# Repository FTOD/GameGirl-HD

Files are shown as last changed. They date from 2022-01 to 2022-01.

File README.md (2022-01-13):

GameGirl Hardware Development
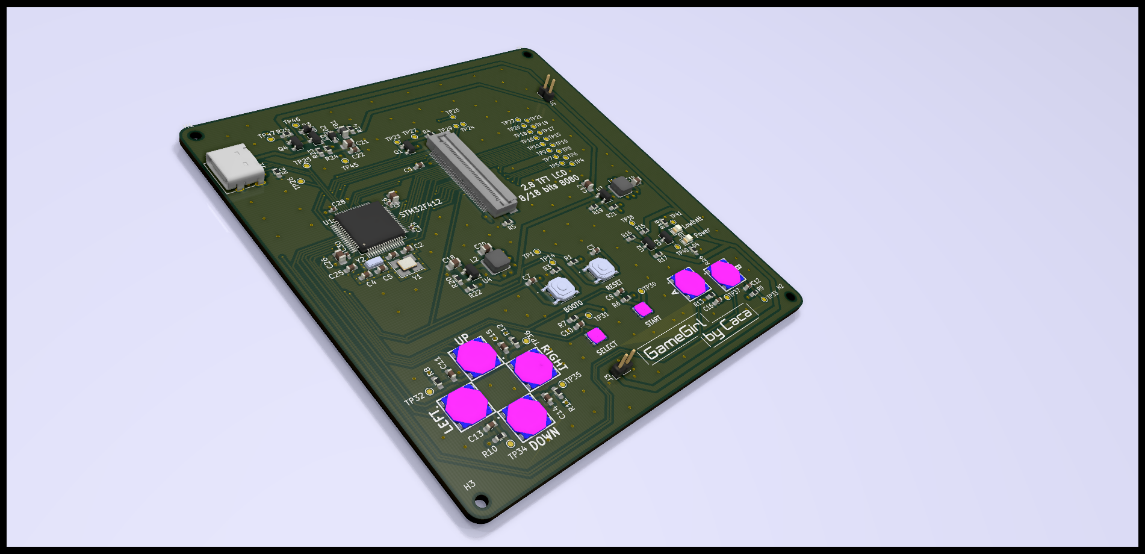
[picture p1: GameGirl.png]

[Schematics as PDF](schematics.pdf)
## To do better in the next version:
-   Impedance matching of D+/D- lines of USB
-   Use Lipo or Li-ion battery with embedded charger circuit
-   Embed the On-Off switch (some PMIC may have this kind of feature with tactile switches)
## License

Copyright (c) Caca 2021-1.
This source and all design files in the GameGirl project: https://github.com/FTOD/GameGirl-HD describe Open Hardware and is licensed under the CERN-OHL-P
v2
You may redistribute and modify this documentation and make products
using it under the terms of the CERN-OHL-P v2 (https:/cern.ch/cern-ohl).
This documentation is distributed WITHOUT ANY EXPRESS OR IMPLIED
WARRANTY, INCLUDING OF MERCHANTABILITY, SATISFACTORY QUALITY
AND FITNESS FOR A PARTICULAR PURPOSE. Please see the CERN-OHL-P v2
for applicable conditions

please refer to [cern_ohl_p_v2_howto.pdf](cern_ohl_p_v2_howto.pdf) for how to deal with this license.

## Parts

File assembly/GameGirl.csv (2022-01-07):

Designator | Quantity | Value | Footprint | LCSC Part#
C1, C2, C4, C5, | 4 | 20pF | 603 | C1648
C9, C10, C11, C12, C13, C14, C15, C16, | 8 | 10nF | 603 | C57112
C3, C7, | 2 | 100pF | 603 | C14858
C6, C17, C18, | 3 | 4.7uF | 805 | C1779
C8, | 1 | 1uF | 603 | C28323
C19, C20, C21, C26, | 4 | 10uF | 805 | C440198
C22, C25, | 2 | 100nF | 603 | C14663
C27, C28, C29, C30, | 4 | 100nF | 402 | C307331
D1 | 2 | LED | 805 | C2296
D4 | 2 | LED | 805 | C2297
D2, D3, | 2 | D_Shockley | SOD-323 | C191023
FB1, | 1 | GZ2012D601TF | 805 | C1017
J1, | 1 | USB_C(U262-161N-4BVC11) | USB-3.1-SMD | C319148
J2, | 1 | FH28-40S-0.5SH(07) | FPC-SMD | C424677
L1, L2, | 2 | 2.2uH | IND-SMD | C136245
Q1, Q2, | 2 | AO3400(NMOS) | SOT-23 | C20917
Q3, Q4, | 2 | AO3401 | SOT-23 | C15127
R1, R3, R6, R7, R8, R9, R10, R11, R12, R13, R14, R16, R23, R25, | 14 | 10K | 603 | C25804
R2, | 1 | 5.1K | 603 | C23186
R4, | 1 | 10R | 603 | C22859
R5, | 1 | 20K | 603 | C4184
R15, | 1 | 3.3K | 603 | C22978
R17, | 1 | 1K | 603 | C21190
R18, R26, | 2 | 100R | 603 | C22775
R19, R20, | 2 | 100K | 603 | C25803
R21, | 1 | 430K | 603 | C25969
R22, | 1 | 200K | 603 | C25811
R24, | 1 | 4.7K | 603 | C23162
SW1, SW2, | 2 | TS-1187 | SMD-SW-4_5.1x5.1x1.5 | C318884
SW3, SW4, | 2 | SKSHAAE010 | SW-SMD | C262415
SW5, SW6, SW7, SW8, SW9, SW10, | 6 | SKRRAAE010 | KEY-SMD | C97437
U1, | 1 | STM32F412RET6 | LQFP-64_10.0x10.0x0.5P | C89374
U2, | 1 | TL431 | SOT-23-3 | C350683
U3, U4, | 2 | TLV62569DBV | SOT-23-5 | C141836
Y1, | 1 | X322525-25MHz 12pF | SMD-3225_4P | C9006
Y2, | 1 | FC135-32.768kHz 12.5pF | SMD-3215_2P | C32346

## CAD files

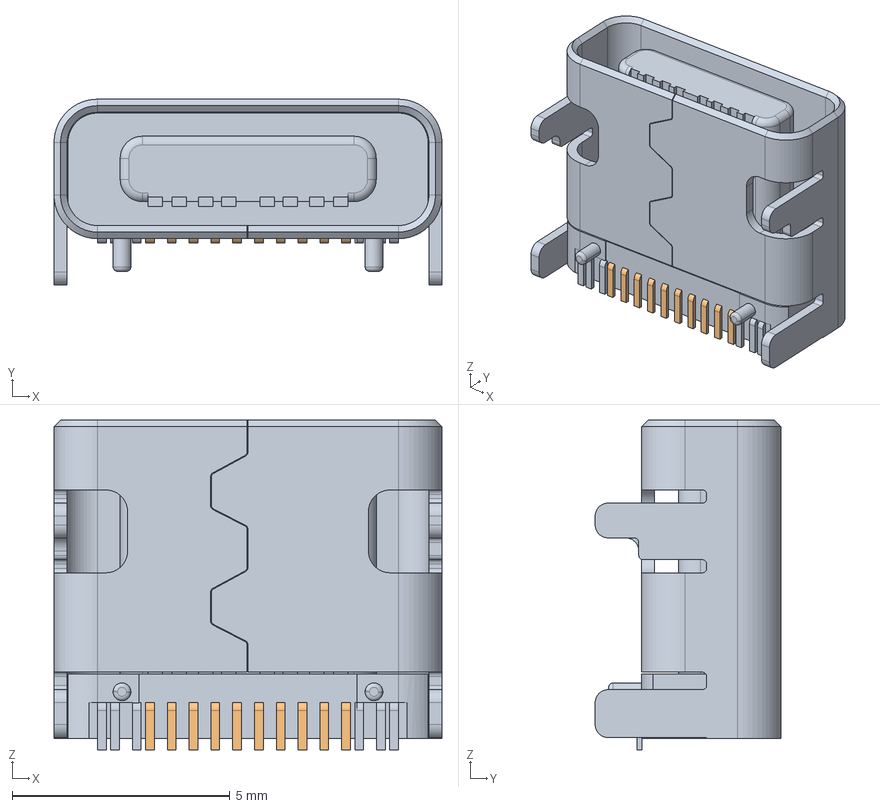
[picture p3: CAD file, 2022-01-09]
3D/u262-161n-4bvc11.stp
8.90 x 4.26 x 7.56 mm

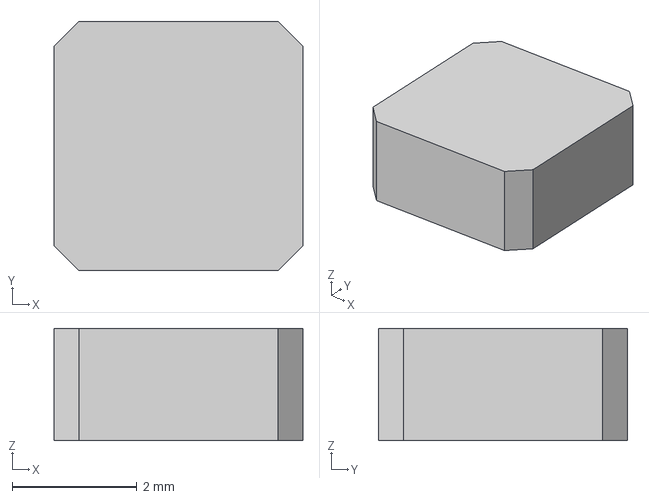
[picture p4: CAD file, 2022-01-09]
3D/VLCF4020.step
4.00 x 4.00 x 1.80 mm

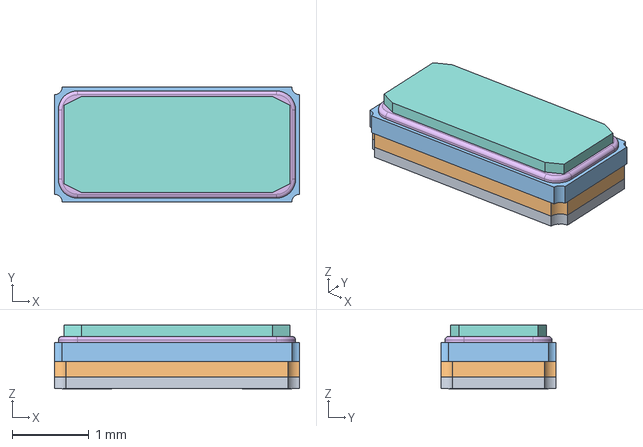
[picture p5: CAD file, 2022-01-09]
FC-135.step
3.20 x 1.50 x 0.831 mm

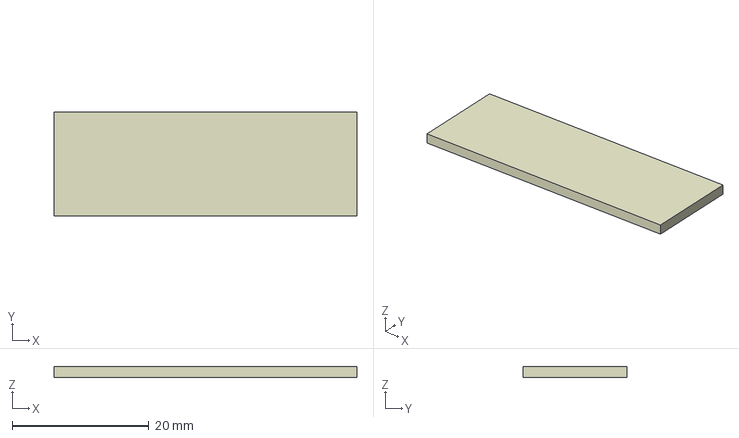
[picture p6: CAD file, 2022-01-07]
3D/Pcb.step
44.3 x 15.2 x 1.58 mm

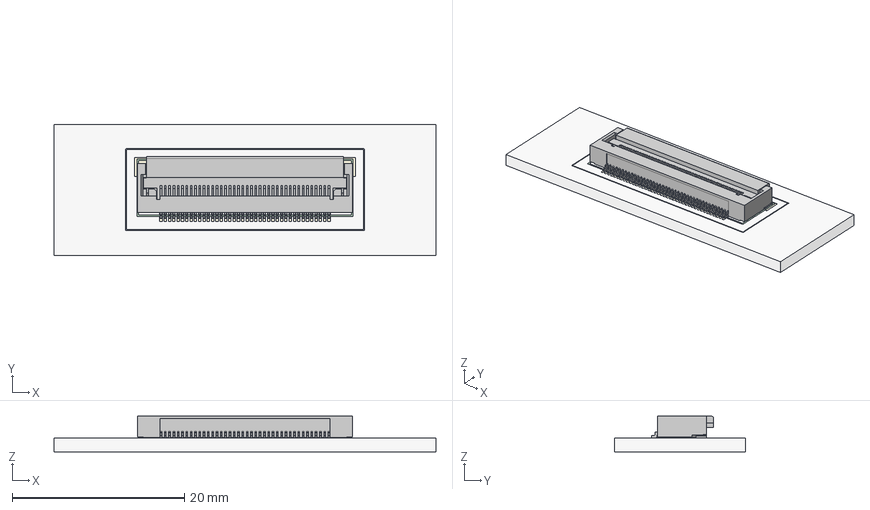
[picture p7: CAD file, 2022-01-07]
3D/40PFFP-worked.FCStd
44.3 x 15.2 x 4.14 mm
FCrtYd
FFab
FrontSilk
TopPads
Pcb
FH28-40S-0.5SH_Èª

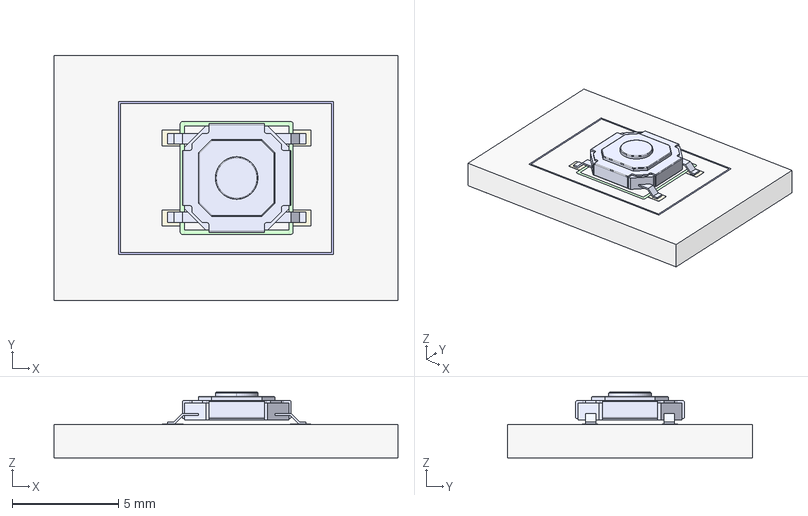
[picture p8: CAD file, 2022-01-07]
3D/TS-1187A-B-A-B-worked.FCStd
16.2 x 11.5 x 3.09 mm
FCrtYd
FFab
FrontSilk
TopPads
Pcb
TS-1187A-B-A-B

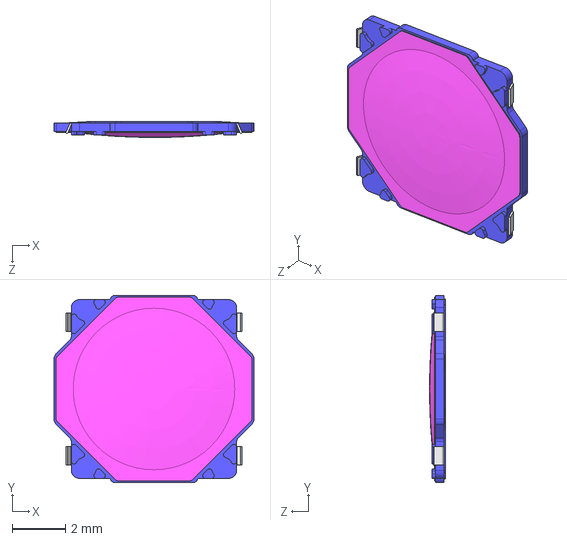
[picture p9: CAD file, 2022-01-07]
3D/SKRRAA.STEP
7.50 x 7.03 x 0.6 mm

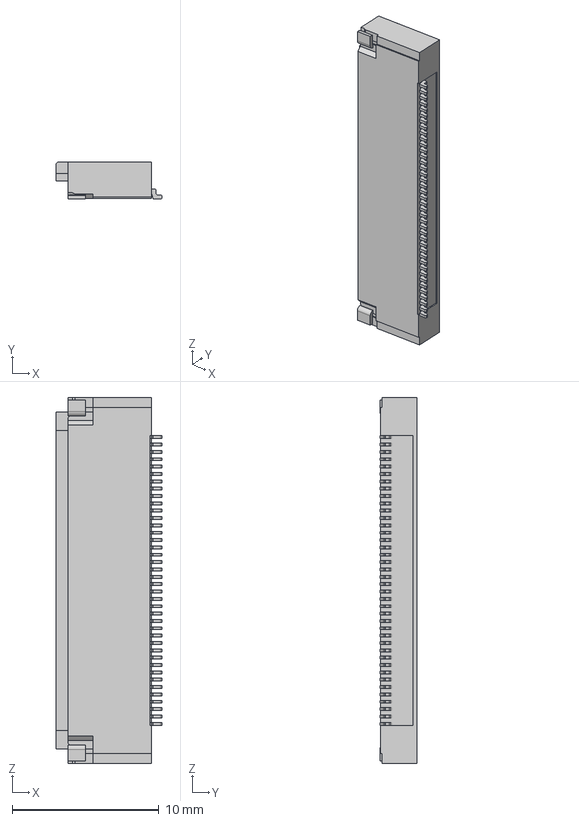
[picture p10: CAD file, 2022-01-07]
3D/FH28-40S-0.5SH.stp
7.20 x 2.55 x 24.9 mm

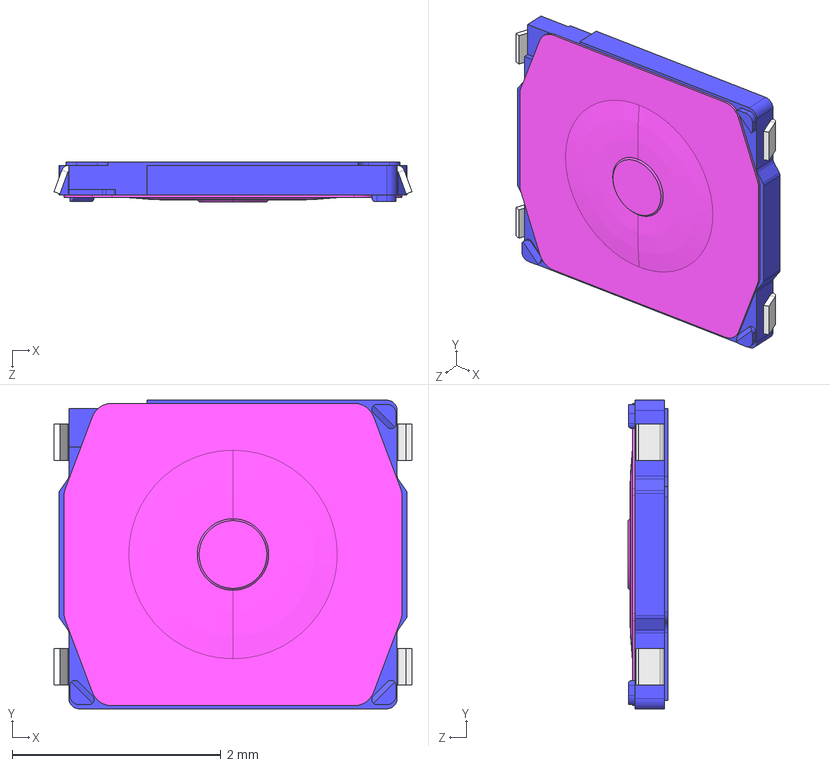
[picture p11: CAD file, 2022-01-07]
3D/SKSHAA.STEP
3.43 x 2.96 x 0.379 mm

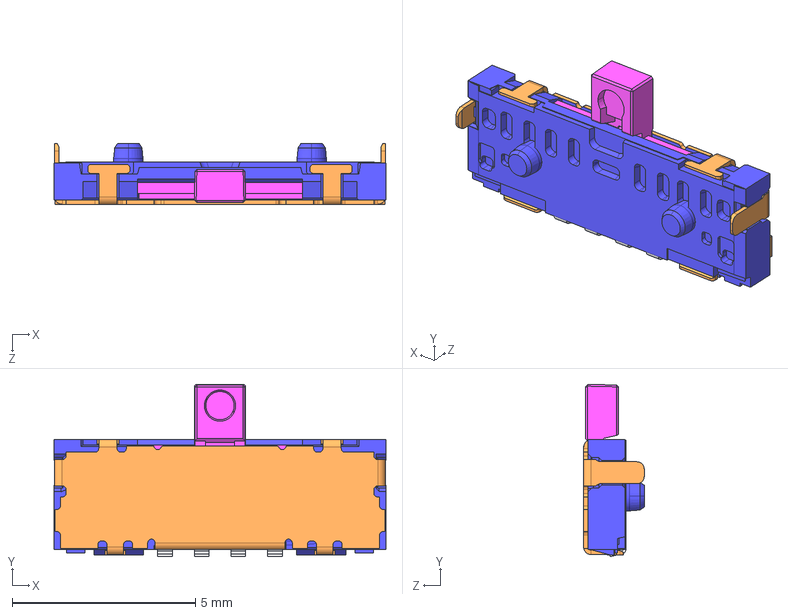
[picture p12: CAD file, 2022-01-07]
3D/SSAG230200.STEP
9.05 x 4.70 x 1.65 mm

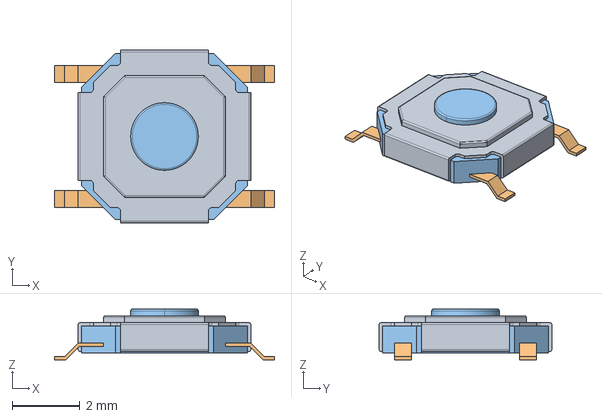
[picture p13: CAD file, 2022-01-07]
3D/TS-1187A-B-A-B.step
6.50 x 5.10 x 1.50 mm

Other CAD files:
U262-161XN-4BVC11.step
3D/FC-135.stp
3D/TS-1187A-B-A-B.stp
FC-135.FCStd
U262-161N-4BVC11.FCStd

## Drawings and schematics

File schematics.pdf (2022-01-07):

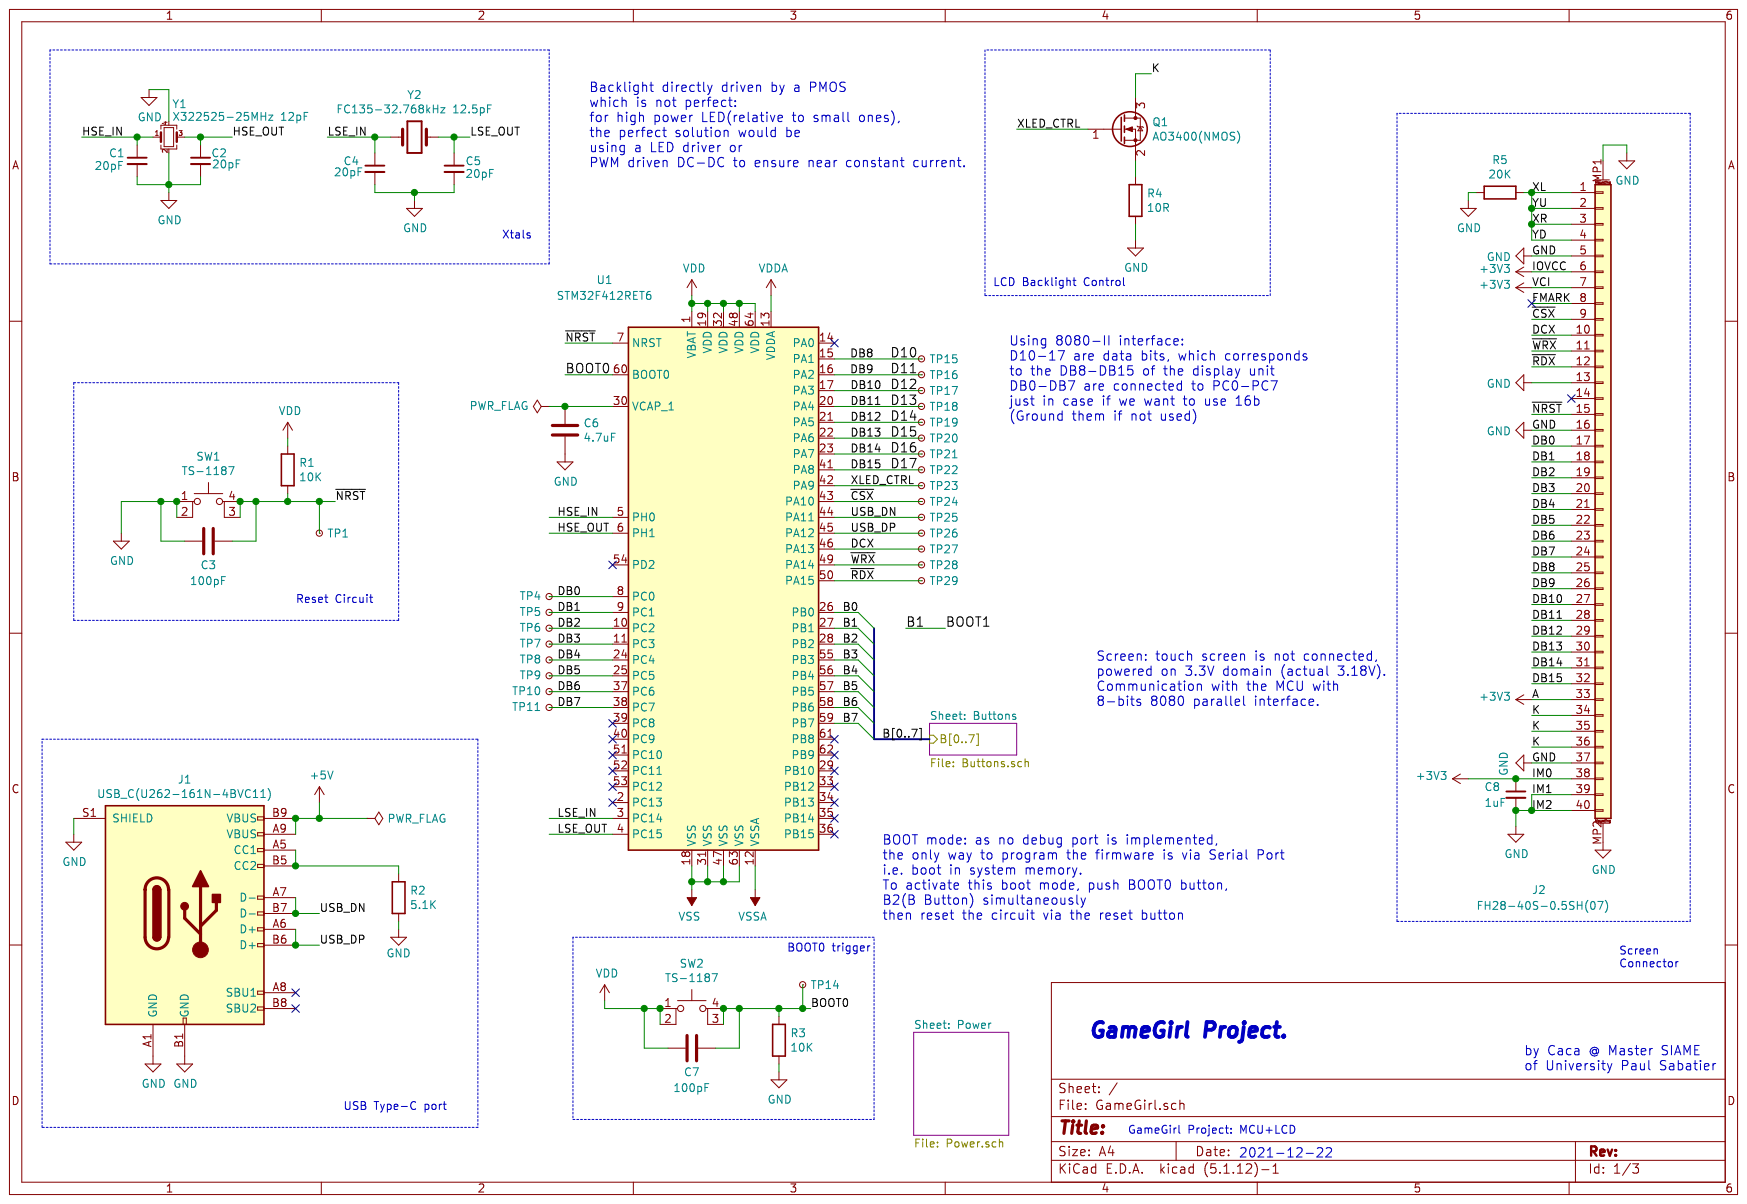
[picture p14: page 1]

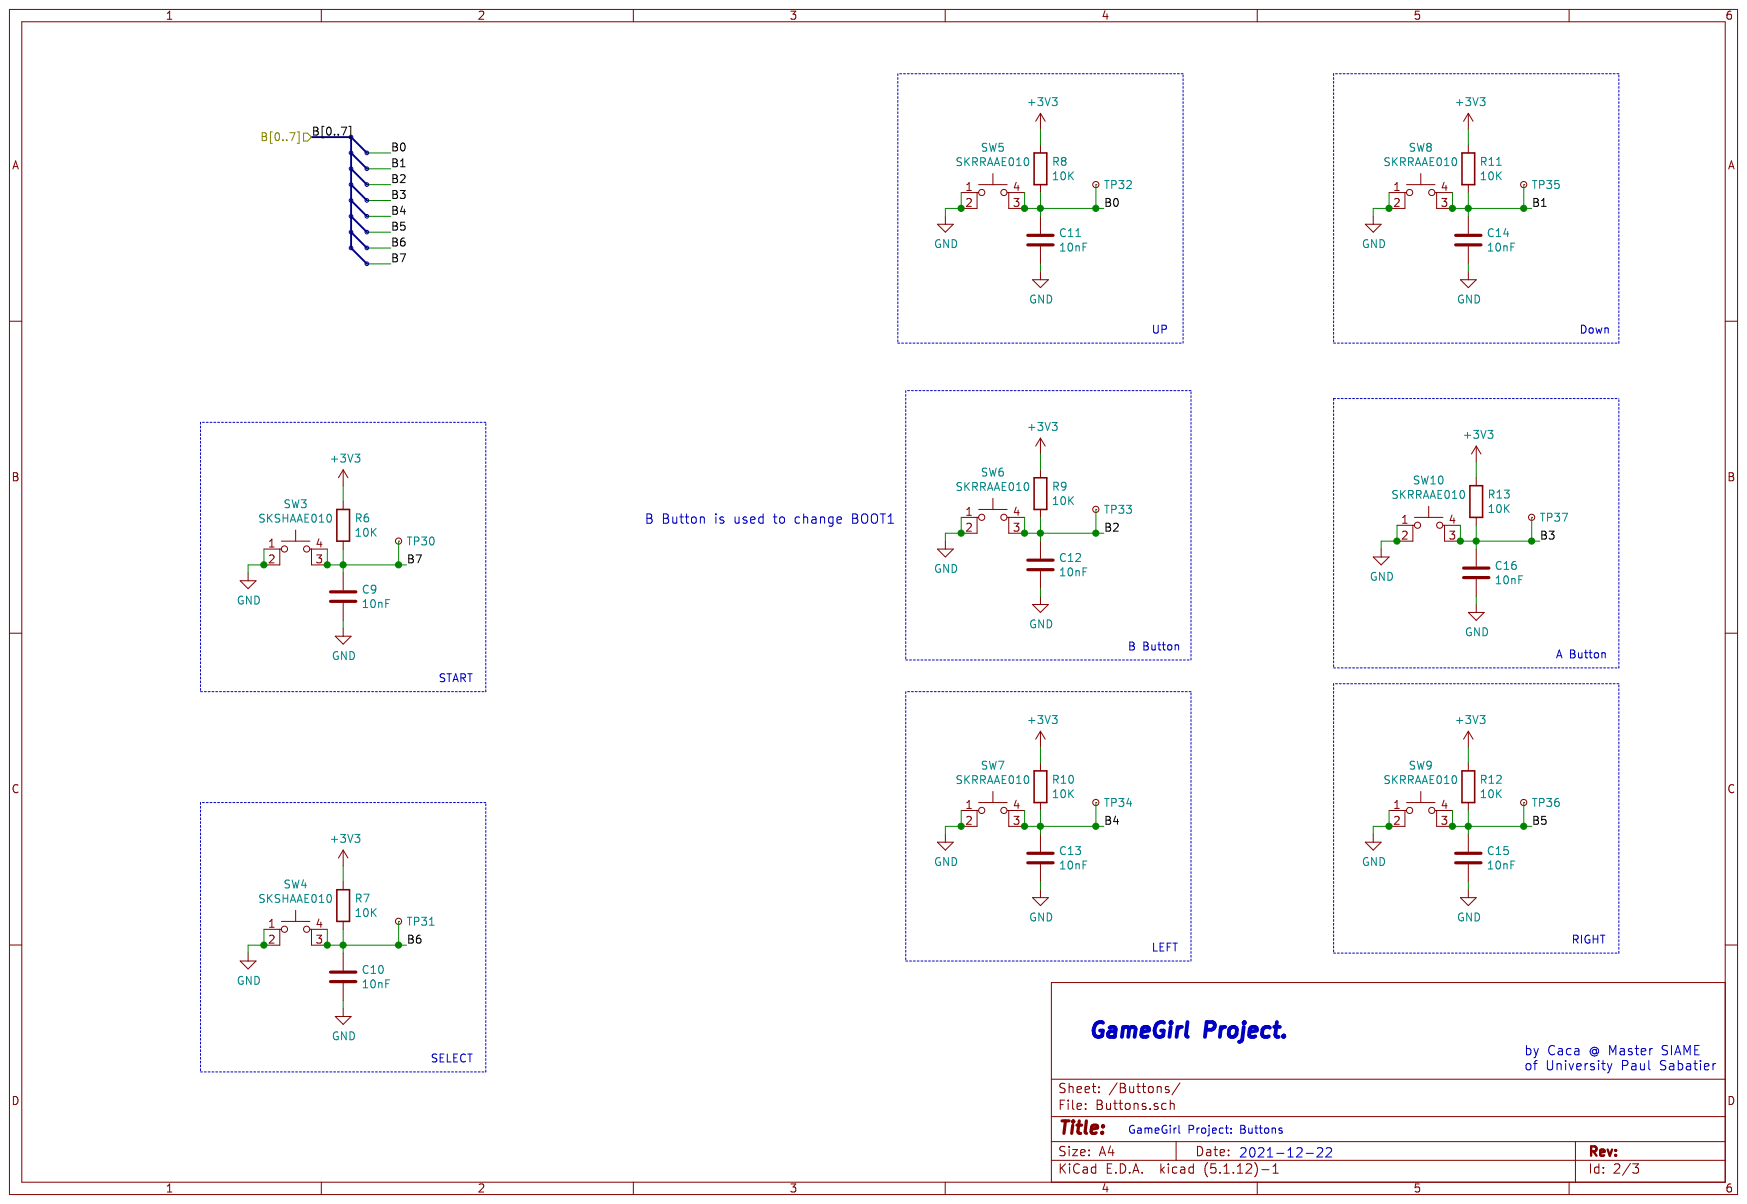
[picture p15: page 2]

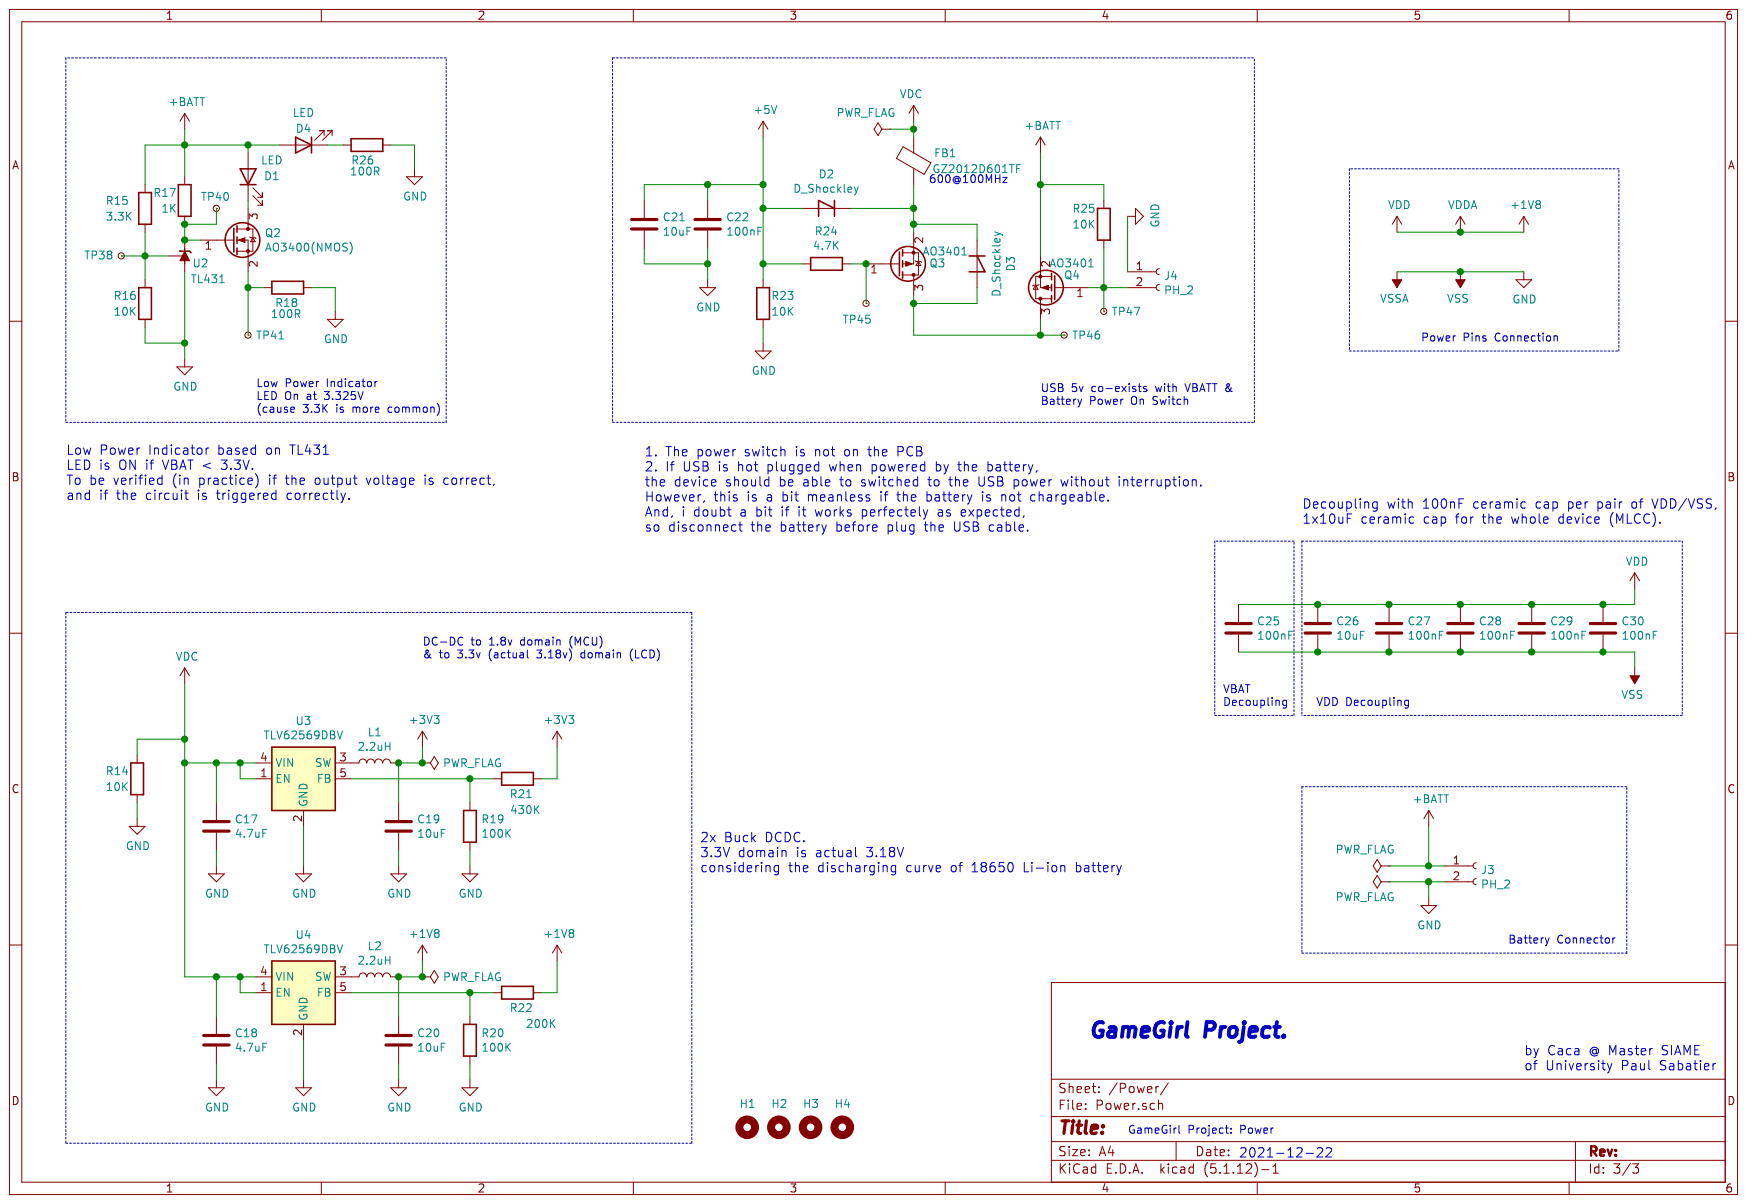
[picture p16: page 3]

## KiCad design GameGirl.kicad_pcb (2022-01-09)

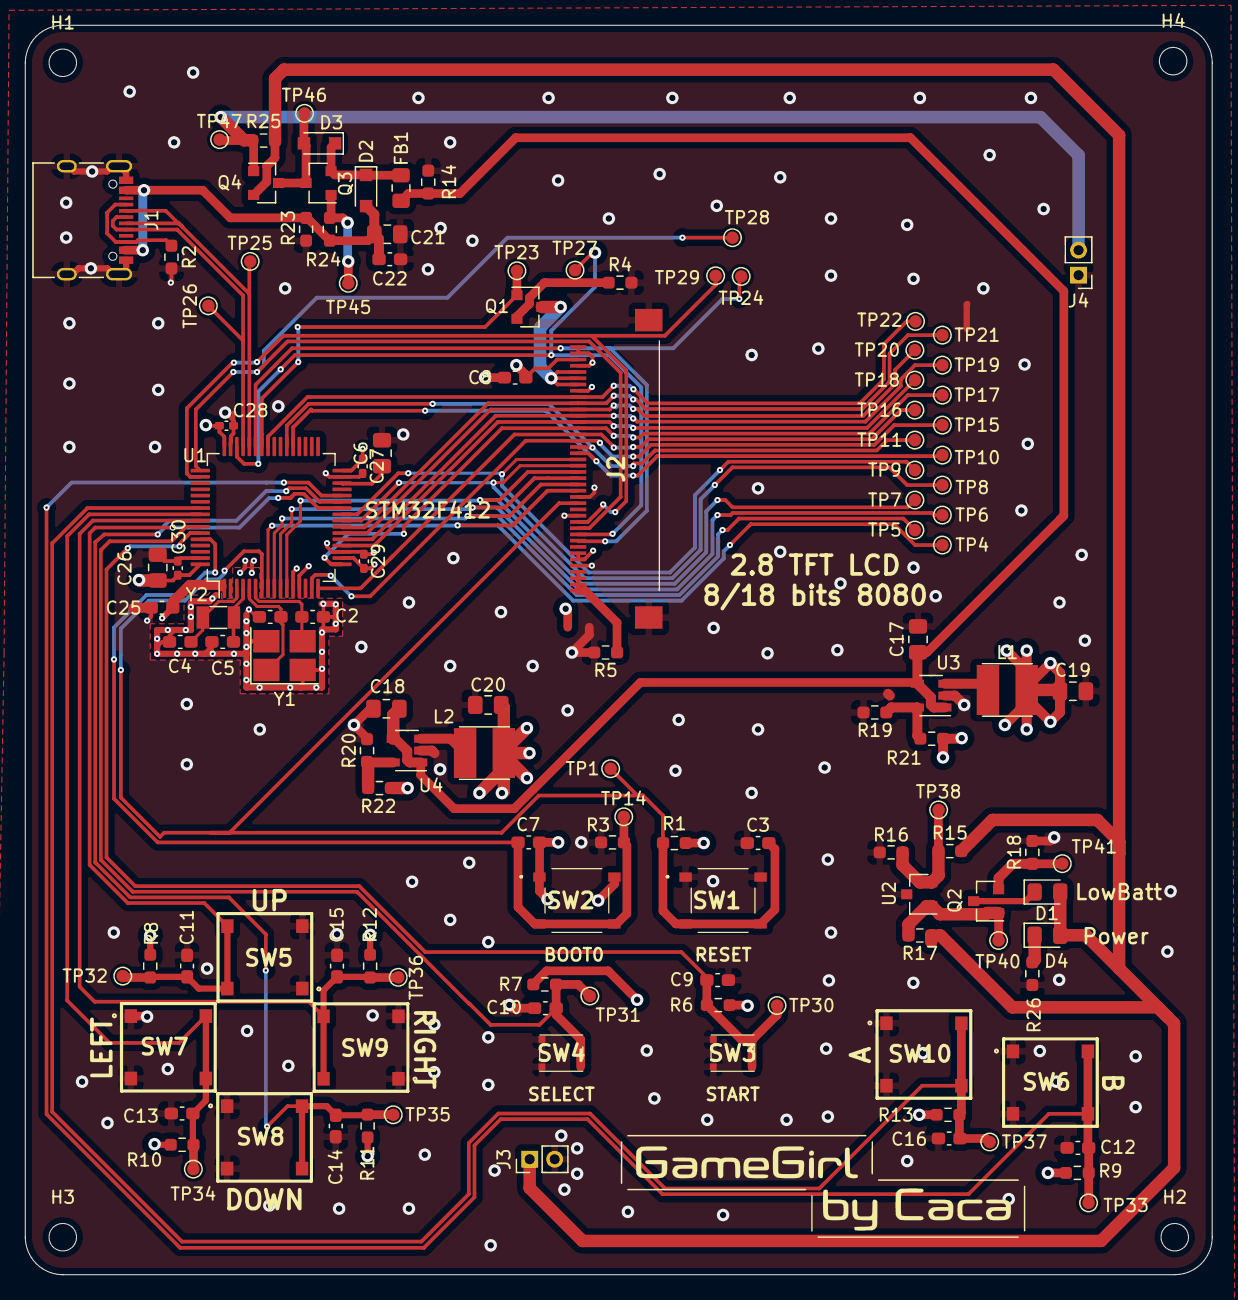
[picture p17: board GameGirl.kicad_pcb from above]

Board: 4 copper layers, 95.0 x 100.0 mm, 128 parts (0 on the bottom side), 61 nets.

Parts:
C1, C2, C4, C5: 20pF; C_0603_1608Metric_Pad1.08x0.95mm_HandSolder
C3, C7: 100pF; C_0603_1608Metric_Pad1.08x0.95mm_HandSolder
C6, C17, C18: 4.7uF; C_0805_2012Metric_Pad1.18x1.45mm_HandSolder
C8: 1uF; C_0603_1608Metric_Pad1.08x0.95mm_HandSolder
C9, C10, C11, C12, C13, C14, C15, C16: 10nF; C_0603_1608Metric_Pad1.08x0.95mm_HandSolder
C19, C20, C21, C26: 10uF; C_0805_2012Metric_Pad1.18x1.45mm_HandSolder
C22: 0.1uF; C_0603_1608Metric_Pad1.08x0.95mm_HandSolder
C25: 100nF; C_0603_1608Metric_Pad1.08x0.95mm_HandSolder
C27, C28, C29, C30: 100nF; C_0402_1005Metric_Pad0.74x0.62mm_HandSolder
D1, D4: LED; LED_0805_2012Metric_Pad1.15x1.40mm_HandSolder
D2, D3: D_Shockley; D_SOD-323_HandSoldering
FB1: GZ2012D601TF; L_0805_2012Metric_Pad1.15x1.40mm_HandSolder
H1, H2, H3, H4: MountingHole; MountingHole_2.2mm_M2
J1: USB_C(U262-161N-4BVC11); USB_C_Receptacle_XKB_U262-16XN-4BVC11
J2: FH28-40S-0.5SH(07); FH2840S05SH07
J3, J4: PH_2; PinHeader_1x02_P2.00mm_Vertical
L1, L2: 2.2uH; L_TDK_VLCF4020x
Q1, Q2: AO3400(NMOS); SOT-23
Q3, Q4: AO3401; SOT-23
R1, R3, R6, R7, R8, R9, R10, R11, R12, R13, R14, R16, R23, R25: 10K; R_0603_1608Metric_Pad0.98x0.95mm_HandSolder
R2: 5.1K; R_0603_1608Metric_Pad0.98x0.95mm_HandSolder
R4: 10R; R_0603_1608Metric_Pad0.98x0.95mm_HandSolder
R5: 20K; R_0603_1608Metric_Pad0.98x0.95mm_HandSolder
R15: 3.3K; R_0603_1608Metric_Pad0.98x0.95mm_HandSolder
R17: 1K; R_0603_1608Metric_Pad0.98x0.95mm_HandSolder
R18, R26: 100R; R_0603_1608Metric_Pad0.98x0.95mm_HandSolder
R19, R20: 100K; R_0603_1608Metric_Pad0.98x0.95mm_HandSolder
R21: 430K; R_0603_1608Metric_Pad0.98x0.95mm_HandSolder
R22: 200K; R_0603_1608Metric_Pad0.98x0.95mm_HandSolder
R24: 4.7K; R_0603_1608Metric_Pad0.98x0.95mm_HandSolder
SW1, SW2: TS-1187; TS1187ABAB
SW3, SW4: SKSHAAE010
SW5, SW6, SW7, SW8, SW9, SW10: SKRRAAE010; SKRR
TP1, TP4, TP5, TP6, TP7, TP8, TP9, TP10, TP11, TP14, TP30, TP31, TP32, TP33, TP34, TP35, TP36, TP37: TestPoint_Small; TestPoint_Pad_D1.0mm
TP15, TP16, TP17, TP18, TP19, TP20, TP21, TP22, TP23, TP24, TP25, TP26, TP27, TP28, TP29: DB0; TestPoint_Pad_D1.0mm
TP38: VREF_LED; TestPoint_Pad_D1.0mm
TP40: VTRIG_LED; TestPoint_Pad_D1.0mm
TP41: VLED; TestPoint_Pad_D1.0mm
TP45: 5V TRIG; TestPoint_Pad_D1.0mm
TP46: VBAT OUT; TestPoint_Pad_D1.0mm
TP47: VBATT_TRIG; TestPoint_Pad_D1.0mm
U1: STM32F412RET6; LQFP-64_10x10mm_P0.5mm
U2: TL431; SOT-23
U3, U4: TLV62569DBV; SOT-23-5
Y1: X322525-25MHz 12pF; Crystal_SMD_3225-4Pin_3.2x2.5mm_HandSoldering
Y2: FC135-32.768kHz 12.5pF; Crystal_SMD_3215-2Pin_3.2x1.5mm

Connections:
+1V8: C7.1, C20.1, C25.1, C26.1, C27.1, C28.1, C29.1, C30.1, L2.2, R1.1, R22.2, SW2.1, SW2.2, U1.1, U1.13, U1.19, U1.32, U1.48, U1.64
+3V3: C8.1, C19.1, J2.6, J2.7, J2.33, J2.38, L1.2, R6.1, R7.1, R8.1, R9.1, R10.1, R11.1, R12.1, R13.1, R21.2
+5V: C21.1, C22.1, D2.2, J1.A4, J1.A9, J1.B4, J1.B9, R23.1, R24.1
+BATT: D1.2, D4.2, J3.1, Q4.2, R15.1, R17.1, R25.1
/B0: C11.1, R8.2, SW5.3, SW5.4, TP32.1, U1.26
/B1: C14.1, R11.2, SW8.3, SW8.4, TP35.1, U1.27
/B2: C12.1, R9.2, SW6.3, SW6.4, TP33.1, U1.28
/B3: C16.1, R13.2, SW10.3, SW10.4, TP37.1, U1.55
/B4: C13.1, R10.2, SW7.3, SW7.4, TP34.1, U1.56
/B5: C15.1, R12.2, SW9.3, SW9.4, TP36.1, U1.57
/B6: C10.1, R7.2, SW4.3, SW4.4, TP31.1, U1.58
/B7: C9.1, R6.2, SW3.3, SW3.4, TP30.1, U1.59
/BOOT0: C7.2, R3.1, SW2.3, SW2.4, TP14.1, U1.60
/D10: J2.25, TP15.1, U1.15
/D11: J2.26, TP16.1, U1.16
/D12: J2.27, TP17.1, U1.17
/D13: J2.28, TP18.1, U1.20
/D14: J2.29, TP19.1, U1.21
/D15: J2.30, TP20.1, U1.22
/D16: J2.31, TP21.1, U1.23
/D17: J2.32, TP22.1, U1.41
/DB0: J2.17, TP4.1, U1.8
/DB1: J2.18, TP5.1, U1.9
/DB2: J2.19, TP6.1, U1.10
/DB3: J2.20, TP7.1, U1.11
/DB4: J2.21, TP8.1, U1.24
/DB5: J2.22, TP9.1, U1.25
/DB6: J2.23, TP10.1, U1.37
/DB7: J2.24, TP11.1, U1.38
/DCX: J2.10, TP27.1, U1.46
/HSE_IN: C1.1, U1.5, Y1.1
/HSE_OUT: C2.1, U1.6, Y1.3
/K: J2.34, J2.35, J2.36, Q1.3
/LSE_IN: C4.1, U1.3, Y2.1
/LSE_OUT: C5.1, U1.4, Y2.2
/USB_DN: J1.A7, J1.B7, TP25.1, U1.44
/USB_DP: J1.A6, J1.B6, TP26.1, U1.45
/XL: J2.1, J2.2, J2.3, J2.4, R5.1
/XLED_CTRL: Q1.1, TP23.1, U1.42
/~CSX: J2.9, TP24.1, U1.43
/~NRST: C3.2, J2.15, R1.2, SW1.3, SW1.4, TP1.1, U1.7
/~RDX: J2.12, TP29.1, U1.50
/~WRX: J2.11, TP28.1, U1.49
GND: C1.2, C2.2, C3.1, C4.2, C5.2, C6.2, C8.2, C9.2, C10.2, C11.2, C12.2, C13.2, C14.2, C15.2, C16.2, C17.2, C18.2, C19.2, C20.2, C21.2, C22.2, C25.2, C26.2, C27.2, C28.2, C29.2, C30.2, J1.A1, J1.A12, J1.B1, J1.B12, J1.S1, J2.5, J2.13, J2.16, J2.37, J2.39, J2.40, J2.MP1, J2.MP2, J3.2, J4.1, R2.2, R3.2, R4.2, R5.2, R14.2, R16.2, R18.2, R19.2, R20.2, R23.2, R26.2, SW1.1, SW1.2, SW3.1, SW3.2, SW4.1, SW4.2, SW5.1, SW5.2, SW6.1, SW6.2, SW7.1, SW7.2, SW8.1, SW8.2, SW9.1, SW9.2, SW10.1, SW10.2, U1.12, U1.18, U1.31, U1.47, U1.63, U2.3, U3.2, U4.2, Y1.2, Y1.4
unnamed: C6.1, U1.30
unnamed: D1.1, Q2.3
unnamed: D2.1, D3.1, FB1.2, Q3.2
unnamed: D3.2, Q3.3, Q4.3, TP46.1
unnamed: D4.1, R26.1
unnamed: J1.A5, J1.B5, R2.1
unnamed: J4.2, Q4.1, R25.2, TP47.1
unnamed: L1.1, U3.3
unnamed: L2.1, U4.3
unnamed: Q1.2, R4.1
unnamed: Q2.1, R17.2, TP40.1, U2.1
unnamed: Q2.2, R18.1, TP41.1
unnamed: Q3.1, R24.2, TP45.1
unnamed: R15.2, R16.1, TP38.1, U2.2
unnamed: R19.1, R21.1, U3.5
unnamed: R20.1, R22.1, U4.5
VDC: C17.1, C18.1, FB1.1, R14.1, U3.1, U3.4, U4.1, U4.4

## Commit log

2022-01-07 first commit, almost all files are added, maybe eeds a bit of clean up
    [40PFFP-worked.FCStd, Buttons.sch, FH28-40S-0.5SH.stp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]
2022-01-07 add schematics pdf
2022-01-09 add missing 3D models, new rendering
    [FC-135.FCStd, FC-135.step, FC-135.stp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]
